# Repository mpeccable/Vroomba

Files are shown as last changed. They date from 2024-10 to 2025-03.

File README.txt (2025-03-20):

Hey!

This is the github for Vroomba team ME 72 
The contents of these folders are laid out in the following way:

Vroomba
    |-> Code
    |---> last_yyyymmdd
    |---> last_yyyymmdd
    --> CAD
    |---> last_yyyymmdd
    |---> last_yyyymmdd
    -->README.txt
    -->ME72_DWG_IBARRA

Try to stick to the layout please! 
Mostly we are trying to keep track of how recent a version is 
and who you should ask if you have questions.

All the CAD files are zipped folders with either .stl files 
for 3d printing or solidworks files for design

The ME72_DWG_IBARRA document contains engineering drawings 
for the robot.

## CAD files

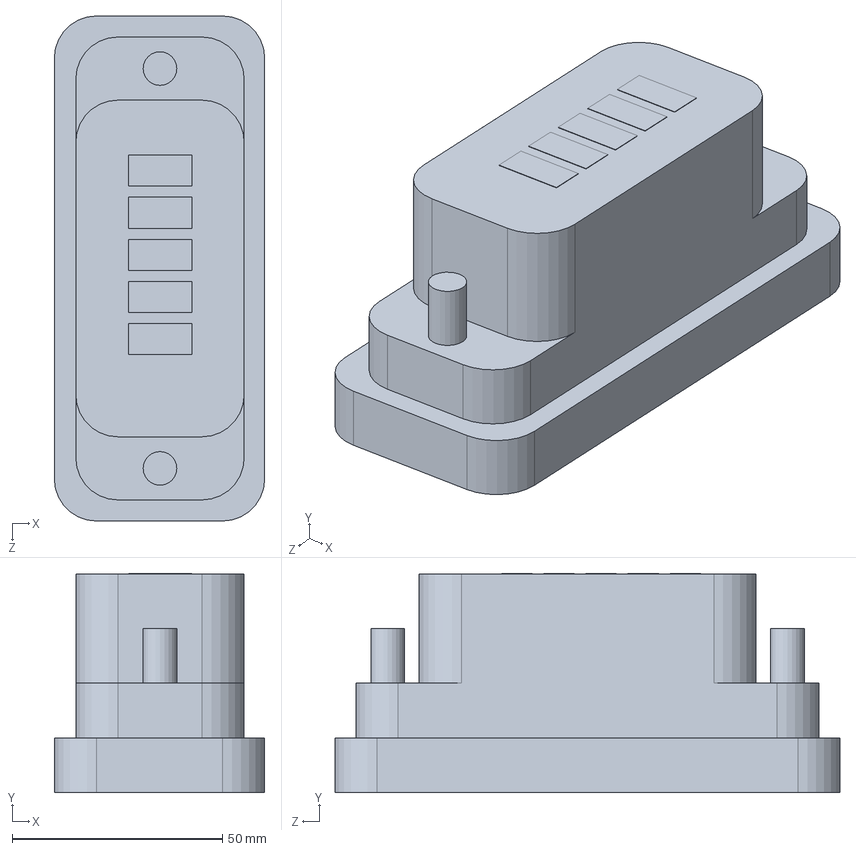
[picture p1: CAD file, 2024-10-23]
CAD/10-22-24 Rachel Individual CAD parts/simplified6wayfusebox.SLDPRT
50.0 x 52.1 x 120.0 mm

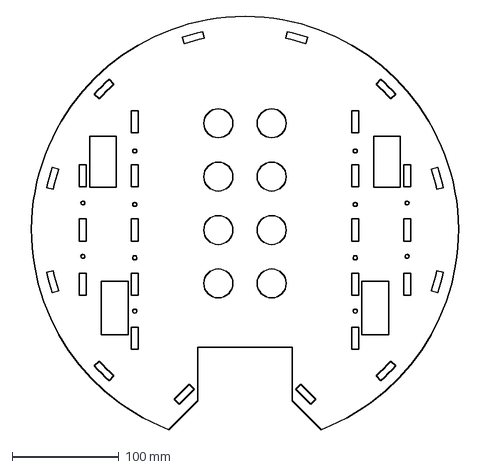
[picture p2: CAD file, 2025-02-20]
CAD/chassis_bot_rev2_alum.DXF
428.3 x 386.9 mm

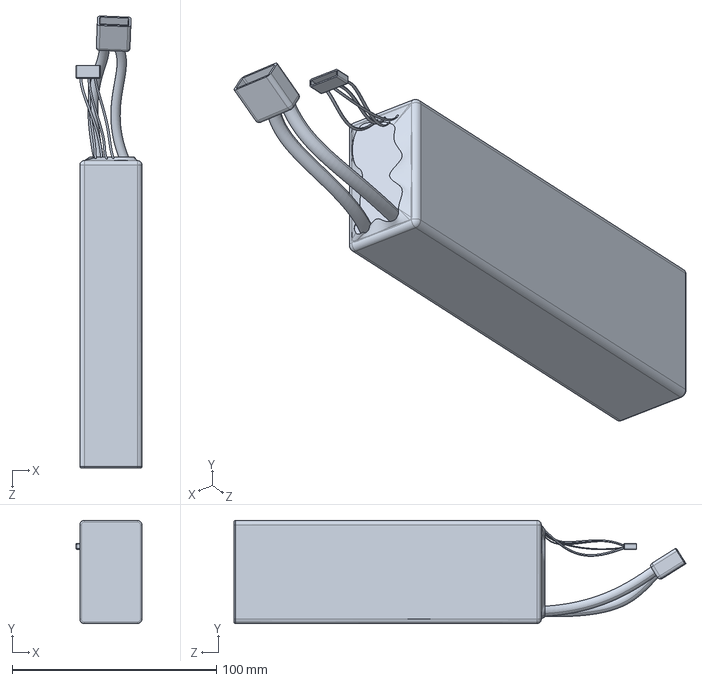
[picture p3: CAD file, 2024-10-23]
CAD/10-22-24 Rachel Individual CAD parts/lipobattery.SLDPRT
32.4 x 50.5 x 221.3 mm

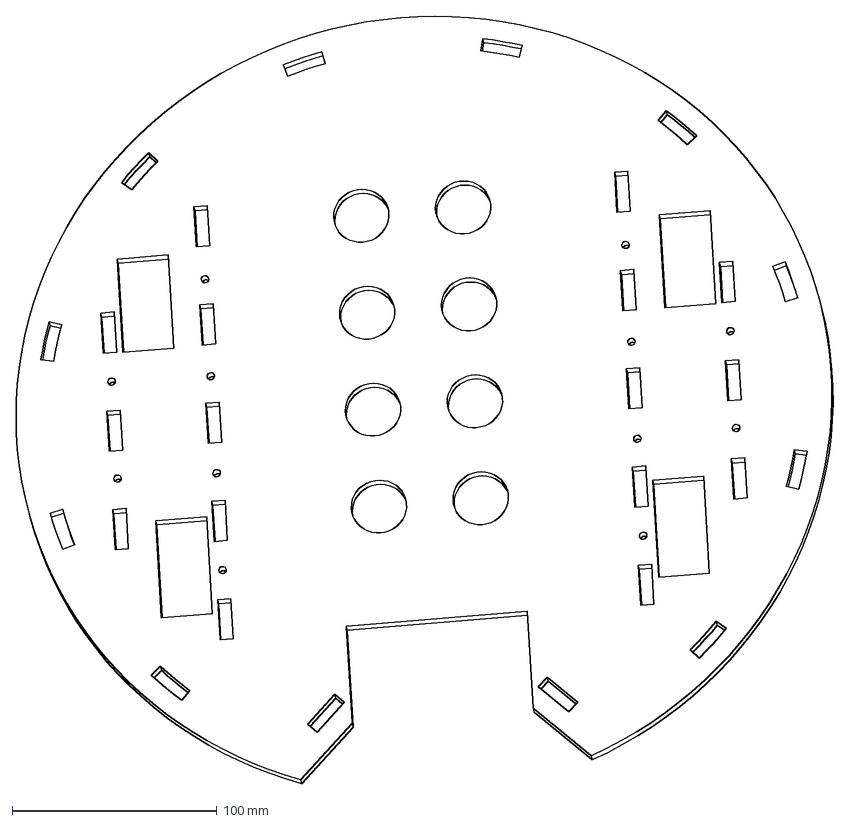
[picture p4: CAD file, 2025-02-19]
CAD/chassis_bot_rev2_aluminum.DXF
399.1 x 374.8 mm

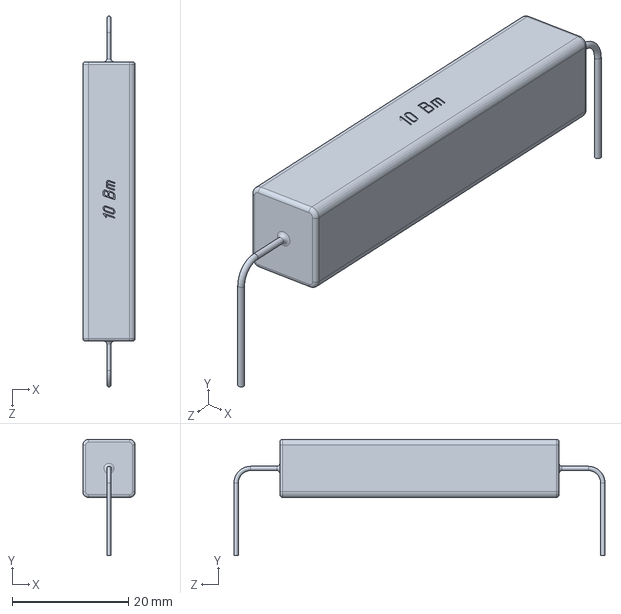
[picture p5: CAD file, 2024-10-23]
CAD/10-22-24 Rachel Individual CAD parts/cementresistor.SLDPRT
9.00 x 20.0 x 63.8 mm

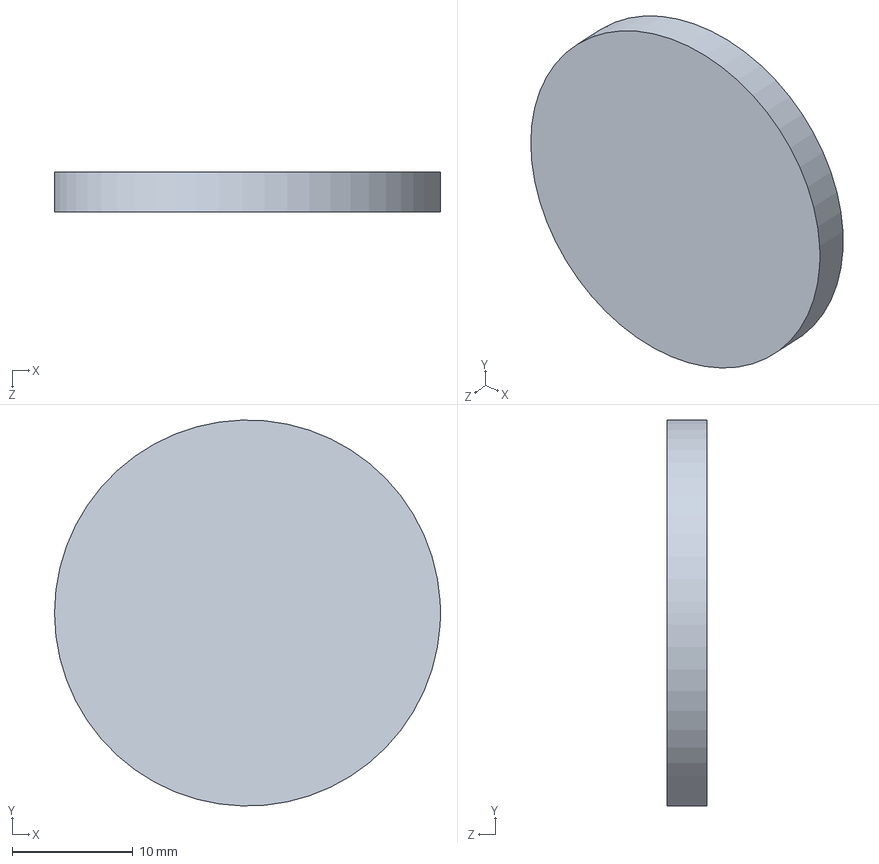
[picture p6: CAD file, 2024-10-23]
CAD/10-22-24 Rachel Individual CAD parts/disc magnets.SLDPRT
32.0 x 32.0 x 3.30 mm

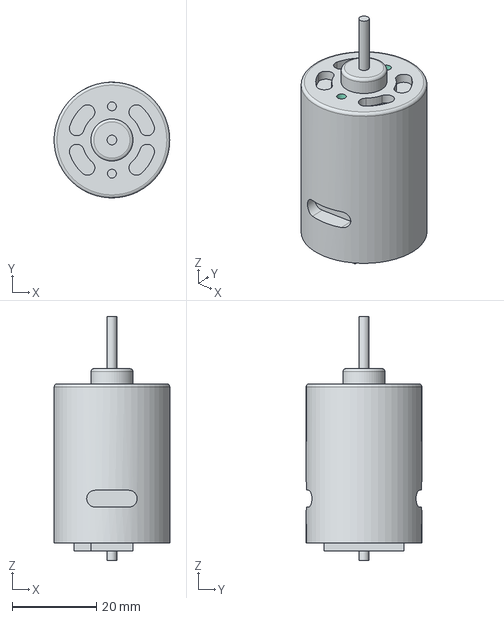
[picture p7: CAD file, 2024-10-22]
CAD/10-22-24 Rachel Individual CAD parts/Transmotec-Cad-L_5-DD (2).stp
27.5 x 27.5 x 58.0 mm

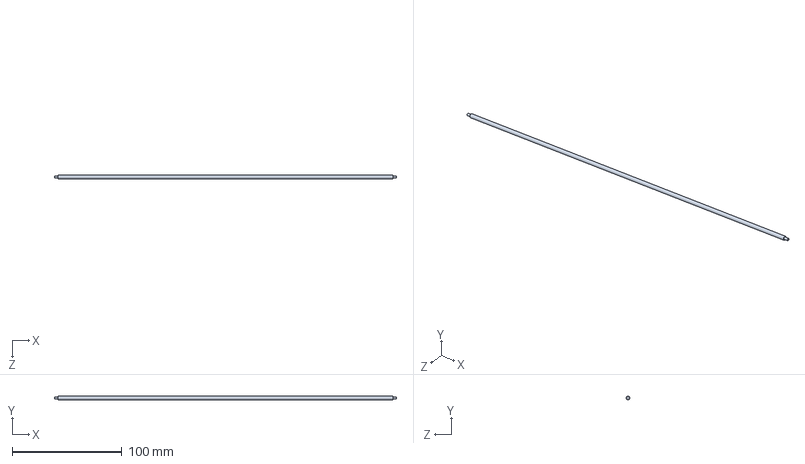
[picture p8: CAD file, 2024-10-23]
CAD/10-22-24 Rachel Individual CAD parts/8251T286_Solid Wire.SLDPRT
311.4 x 3.30 x 3.30 mm

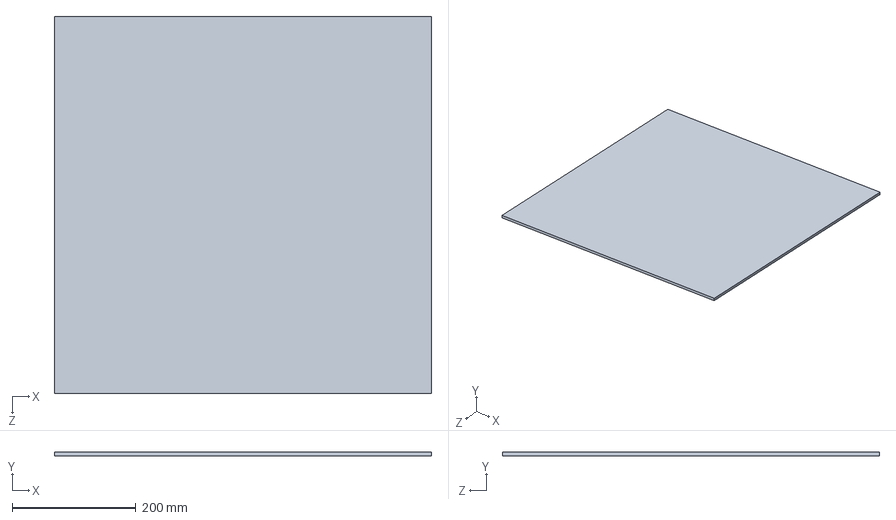
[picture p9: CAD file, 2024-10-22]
CAD/10-22-24 Rachel Individual CAD parts/5865N117_Impact- and Moisture-Resistant HDPE.SLDPRT
609.6 x 6.35 x 609.6 mm

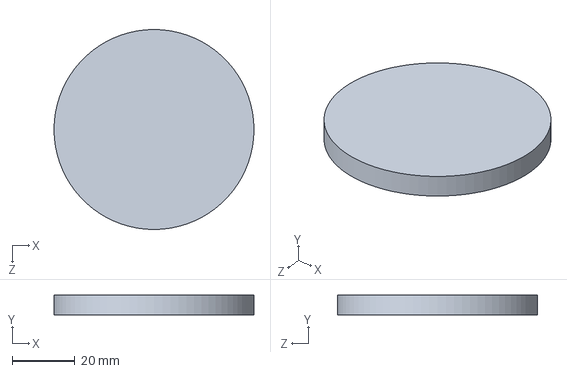
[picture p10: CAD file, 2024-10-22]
CAD/10-22-24 Rachel Individual CAD parts/95495K519_Adhesive-Back Bumpers.SLDPRT
63.5 x 6.35 x 63.5 mm

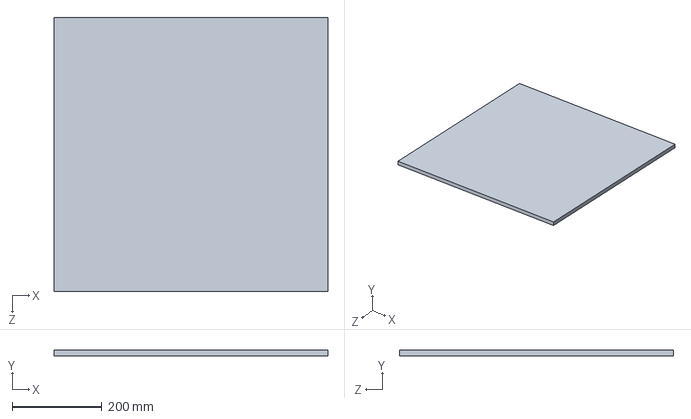
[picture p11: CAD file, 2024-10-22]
CAD/10-22-24 Rachel Individual CAD parts/5865N123_Impact- and Moisture-Resistant HDPE.SLDPRT
609.6 x 12.7 x 609.6 mm

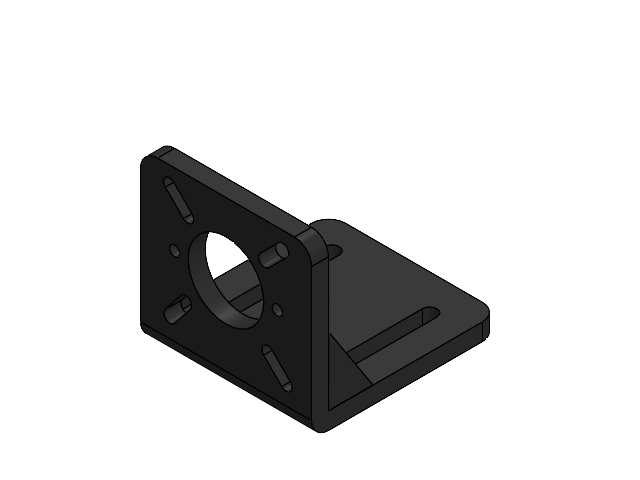
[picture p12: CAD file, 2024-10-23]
CAD/10-22-24 Rachel Individual CAD parts/motormountbracket.SLDASM
first part of bracket
trianglepartofbracket x 2

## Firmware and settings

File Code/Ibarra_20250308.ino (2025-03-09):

#include <RoboClaw.h>

//setting the pins for the H-bridge Motor 
#define IN1 23 
#define IN2 22
#define ENABLEA_PIN 14
#define CH1 27
#define CH6 26
#define CH5 33

// Channel values correspond to sticks and switches on flysky controller
int ch1Value = 0;                 //right stick up/down
int ch5Value = 0;                 //SWd up/down
int ch6Value = 0;                 //SWa up/down

void setup() {
  pinMode(IN1, OUTPUT);           //motor controller direction 1 power
  pinMode(IN2, OUTPUT);           //motor controller direction 2 power
  pinMode(ENABLEA_PIN, OUTPUT);   //motor controller on switch
  pinMode(CH1, INPUT);            //transmitted right stick y axis
  pinMode(CH6, INPUT);            //transmitter switch a
  pinMode(CH5, INPUT);            //transmitter switch d
}

void loop() {
  //SHOOTER MECHANISM
  //Gets a value between 913 (min right stick y) and 2099 (max right stick y)
  ch1Value = pulseIn(CH1, HIGH);

  //Kill switches, Ch6 for whole drive train & shooter Ch5 just for shooter
  //Values either 999/1000 SWd up versus 1999/2000 SWd down
  ch6Value = pulseIn(CH6, HIGH);
  //Values either 999/1000 SWa up versus 1999/2000 SWa down
  ch5Value = pulseIn(CH5, HIGH);

  // Set pins & ENA = 0 - no intake, outake, or shooting occurs 
  if (ch5Value > 1500 | ch6Value < 1500) {
    digitalWrite(IN1, 0);
    digitalWrite(IN2, 0);
    digitalWrite(ENABLEA_PIN, LOW);
  }

  else {
    if (ch1Value < 1300) {
      //spit out puck along the ground
      digitalWrite(ENABLEA_PIN, HIGH);
      analogWrite(IN1, 0);
      analogWrite(IN2, 200);
    }
    else if (ch1Value >= 1300 & ch1Value < 1700) {
      //grab onto puck but dont shoot
      digitalWrite(ENABLEA_PIN, HIGH);
      analogWrite(IN1, 120);
      analogWrite(IN2, 0);
    }
    else if (ch1Value >= 1700) {
      //shoot puck over top
      digitalWrite(ENABLEA_PIN, HIGH);
      analogWrite(IN1, 220);
      analogWrite(IN2, 0);
    }
  }
  delay(5);
}

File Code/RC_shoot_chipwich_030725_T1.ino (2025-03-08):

#include <RoboClaw.h>

// H-bridge motor controller baud rate - 1152000 baud

//setting the pins for the H-bridge Motor 
#define IN1 13 
#define IN2 12
#define ENABLEA_PIN 14
#define CH1 27
#define CH6 26
#define CH5 33
int ch1Value = 0;
int ch5Value;
int ch6Value;

void setup() {
    pinMode(IN1, OUTPUT);
    pinMode(IN2, OUTPUT);
    pinMode(ENABLEA_PIN, OUTPUT);
    pinMode(CH1, INPUT);
    pinMode(CH6, INPUT);
    pinMode(CH5, INPUT);
    
    Serial.begin(115200);
}

void controlShooter(int in1, int in2, bool enable) {
    digitalWrite(ENABLEA_PIN, enable);
    analogWrite(IN1, in1);
    analogWrite(IN2, in2);
}

void loop() {
    //SHOOTER MECHANISM
      ch1Value = pulseIn(CH1, HIGH);
      // Serial.println(ch1Value);

      ch6Value = pulseIn(CH6, HIGH);

      ch5Value = pulseIn(CH5, HIGH);

      Serial.println(ch5Value);

      delay(50);

      //int sensorValue = analogRead(testpin);
      //Serial.println(sensorValue);

    // Set pins & ENA = 0 - no intake, outake, or shooting occurs 
      if ((ch5Value == 999) || (ch5Value == 1000)) {
        controlShooter(0, 0, false);
      }
      
//    // Intake - similar to how pressing "A" was with the bluetooth controller
      else if (ch1Value < 1500){
        controlShooter(100, 0, true); //prev - controlShooter(#, 0, true);
      }
//
//    // Outake - similar to how pressing "X" was with the bluetooth controller
       else if(ch1Value > 1530 ){
       controlShooter(0, 100, true);
     }
//    
//    // Shoot - similar to how pressing "LB" was with the bluetooth controller 
     else if((ch6Value == 999) || (ch6Value == 1000)){
      controlShooter(180, 0, true);
     }
    
     else{
       controlShooter(0, 0, false);
     }
}

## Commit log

2024-10-22 Add files via upload
    Used thinner wheels (0.875"). Slight overlap between panel and chassis but can probs be cut down
2024-10-24 Add files via upload
    Partially Complete CAD file
2024-11-06 Add files via upload
    HTD Pulleys used in bot design included as .stl files. Plating for bambu CFPLA printing included. Original config file and datasheet for pulley sldprt files included.
    [BambuCarbon_HTD_oneside.3mf, CFFFP_HTD_pulleys_one_side.3mf, HTD-5M-9mm-Hex.SLDPRT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]
2024-11-11 Add files via upload
    Arduino Code for Drive train control as tested on 11/8/24
2024-11-13 Add files via upload
    Updated CAD including HTD Pulleys and a first draft of updated transmission plates that include joinery
2024-11-13 Add files via upload
    Updated CAD with base plate and top plate, slight changes to transmission plates
2024-11-14 Add files via upload
    Updated HTD Pulleys per text conversation on afternoon of 11/13/2024. 1 mm Flange width, 10 mm pulley tooth depth
    [HTD-5M-9mm-Hex.xlsx, HTD_12T_10mmPD_1mmF.STL, HTD_18T_10mmPD_1mmF.STL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]
2024-11-18 Add files via upload
    CAD and Laser cutting files for the scalene axle arrangement of our transmission. Consistent with the inter-shaft spacing verified on Fri 11/22.
2024-11-23 Add files via upload
    edits to scalene chassis and transmission plate files to compensate for water jet nozzle width. Adjusted for protomax waterjet. Some slight deviations in nozzle diameter during cutting led to sporadic success of press fits for the bearings. Some are ever slightly too tight, leading to bearing binding.
2024-11-26 Add files via upload
    CAD File for use with waterjet. All waterjet files are in the folder labelled .dxf First file to cut is FlowJet Test Cut. If this file creates a square that is 45 mm x 50 mm and has a hole that will 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
2025-01-07 Add files via upload
    Updated CAD to reflect changes to transmission plates. Isoceles layout for drive axles, enhanced space for electronics, extended joinery to increase mechanical stability, cutouts to reduce weight, and top/base plates adjusted accordingly.
2025-01-07 Add files via upload
    quick error fixes.
    Notes:
    If your computer is not identifying the esp32 module you are connecting, ensure you have downloaded the cp210x drivers from the link at the bottom of the document
    To use this code one must add the additional board manager links (bottom of this message) to Arduino IDE > File > Preferences > Additional Board Manager URLs >
    When uploading to esp-32, ensure that you have selected tools > board > esp32_bluepad32 > Node32s
    When uploading if the only output you see is "Connecting...." press the boot button on the esp32 module ONCE and continue waiting
    https://www.silabs.com/developer-tools/usb-to-uart-bridge-vcp-drivers?tab=downloads
    htt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
2025-01-13 Add files via upload
    First draft of CAD for FDR. Does not include any extras for electronics or mounting of electronics. All other systems finalized, with the exception of actuation on the intake for the shooter.
2025-01-13 Add files via upload
    working code for esp32CAM on Maxx's home wifi. Note, wifi parameters ssid and password must be modified to account for changes to network available for CAM to connect to.
    [partitions.csv]
2025-01-15 Add files via upload
    Updates including significant weight reduction. Current estimates project between 13 and 14 lbs per bot
2025-01-17 Add files via upload
    Additional CAD upload containing models for the T series pulleys as well
2025-01-21 Add files via upload
    Small subset of CAD directory containing drawing files for use with laser cutter and water jet
2025-01-22 Add files via upload
    For driving forward and backwards. To do:
    1. Add code for steering (channel mixing)
    2. Add kill switch
    3. Include safety dead-zones for channels
    4. Start pseudocode for shooter control
2025-01-22 Add files via upload
    No changes to main assembly. Contains updated cutting guides for facing the urethane flywheel and actuator, and cutting guide for precise hex shafts.
2025-01-25 Add files via upload
    Controller code updated with kill switch setup, subject to change with more insight into the mixing for steering capabilities
2025-02-04 Add files via upload
    Folder containing an updated Shooter profile plate for mdf testing along with 3D Models for HTD pulleys compatible with shooter design and drivetrain.
2025-02-05 Add files via upload
    Extra CAD Files to finish shooter prototype
2025-02-05 Add files via upload
    Quick CAD Dump for all components
2025-02-07 Add files via upload
    CAD represents overhaul of shooter design. Chassis still needs to be updated to compensate for these changes
2025-02-07 Add files via upload
    Anotha one. We da best CAD
2025-02-11 Add files via upload
    Electronics mounts and enclosure
2025-02-11 Add files via upload
    test code for servo
2025-02-12 Add files via upload
    CAD directory for DJ contingency. Includes part files and stls needed for completion of assembly
2025-02-19 Add files via upload
    Includes aluminum plate
2025-02-19 Add files via upload
    Prints out (in Serial Monitor) the address of the bluetooth controller once you connect it to a esp32
2025-02-23 Electronics enclosures rev2
    STP files in 3DP folders
    In VertBoardMount.sldprt, use configurations/Excel design table to change the hole spacings for different boards, if needed
2025-02-26 Updated Roboclaw and ESP32 mounts
2025-03-01 DXF files for fin and sidewall
    Use chassis_sidewall_shaved for joinery that is undersized for the top/base plate notches
2025-03-05 Add files via upload
    waterjet files for updated shooter and flanges for updated drivetrain drive pulleys
2025-03-05 Add files via upload
    Files to print on Markforged printer per Brittany's request
2025-03-08 Add files via upload
    ESP32 Chipwich shooter controls coded for intake, out-take, shooting and kill-switch. Will tweak numbers as needed
2025-03-18 Final Rev of CAD
    Final CAD of Biscoff/Shooter. Includes drawings as a pdf, slddrw files, sldasm file, as well as individual sldprt files.
